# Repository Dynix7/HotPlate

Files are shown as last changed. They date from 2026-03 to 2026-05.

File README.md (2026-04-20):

# HotPlate
This is a design for an solder reflow hotplate controlled by an RP2040.

# Why I Made It
I made this PCB since I plan to solder more components in the future. But I currently only have an solder iron which is too big for smaller SMD components, so I can use this to easily solder those smaller components.

# Picture
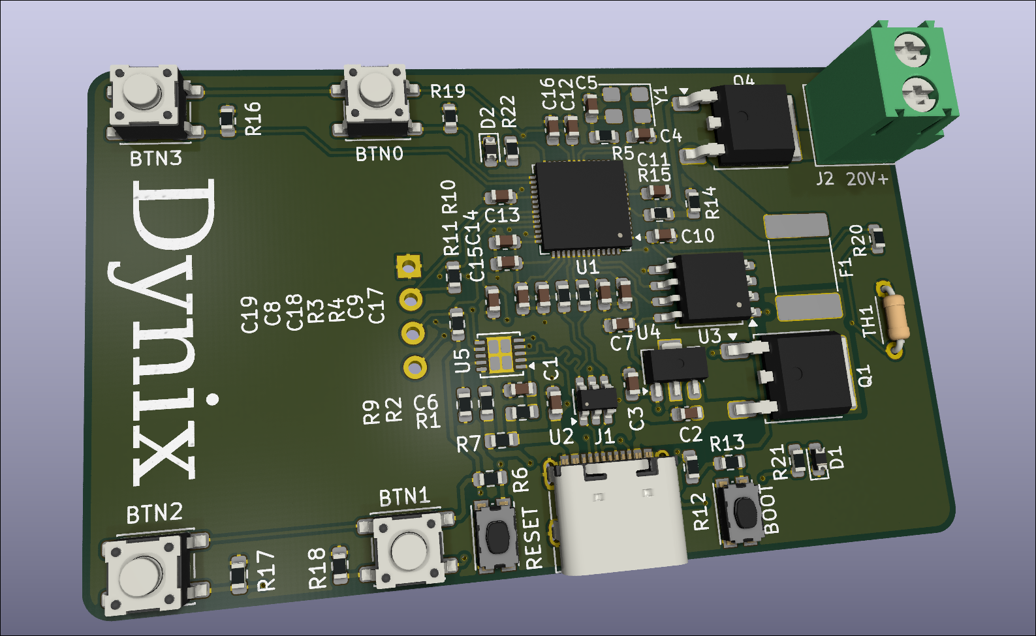
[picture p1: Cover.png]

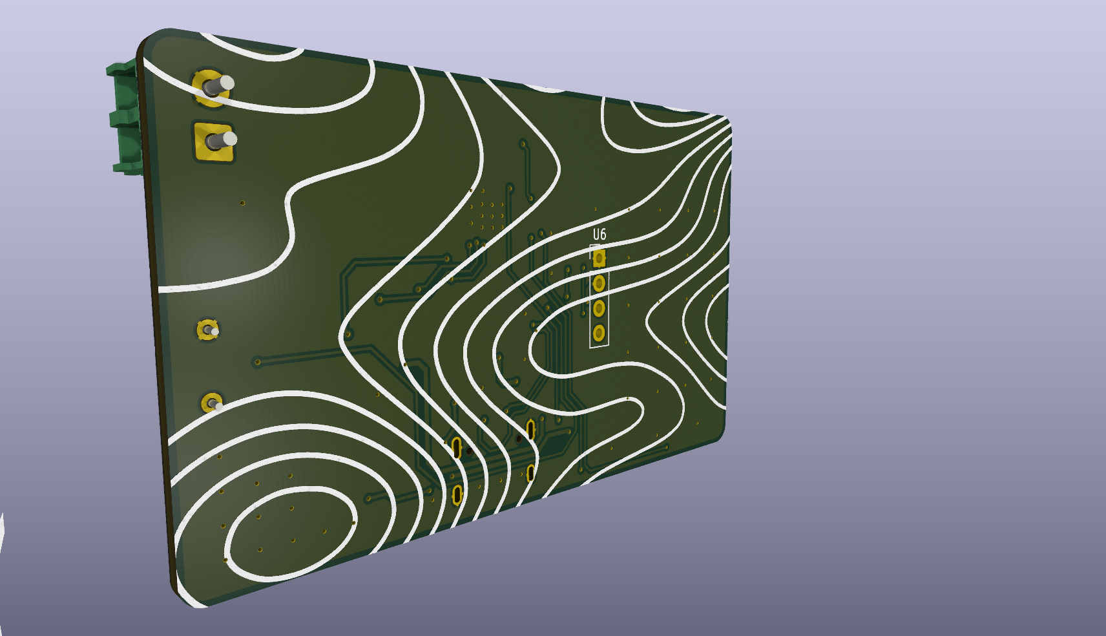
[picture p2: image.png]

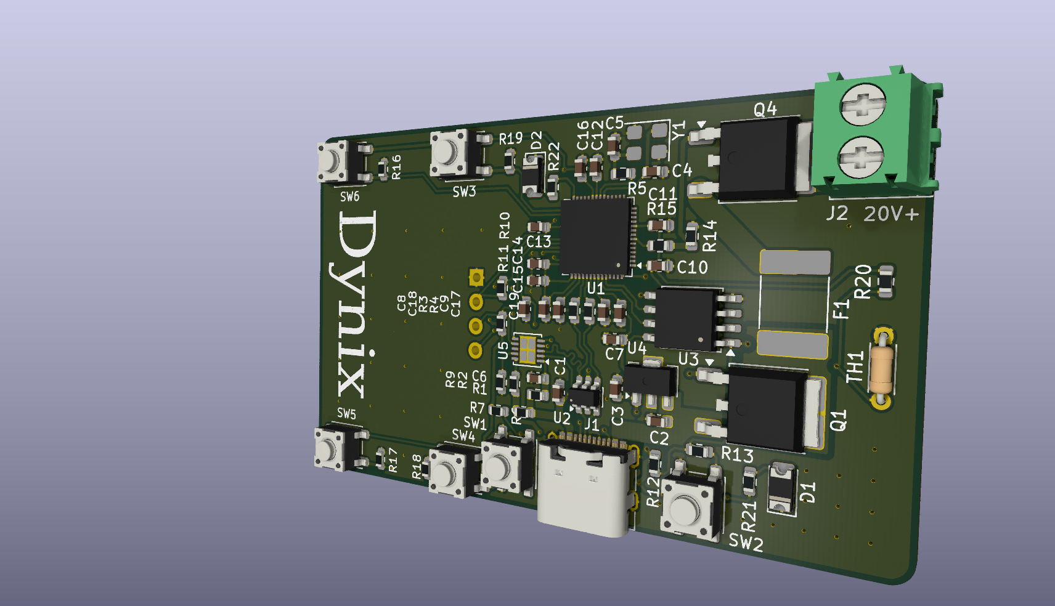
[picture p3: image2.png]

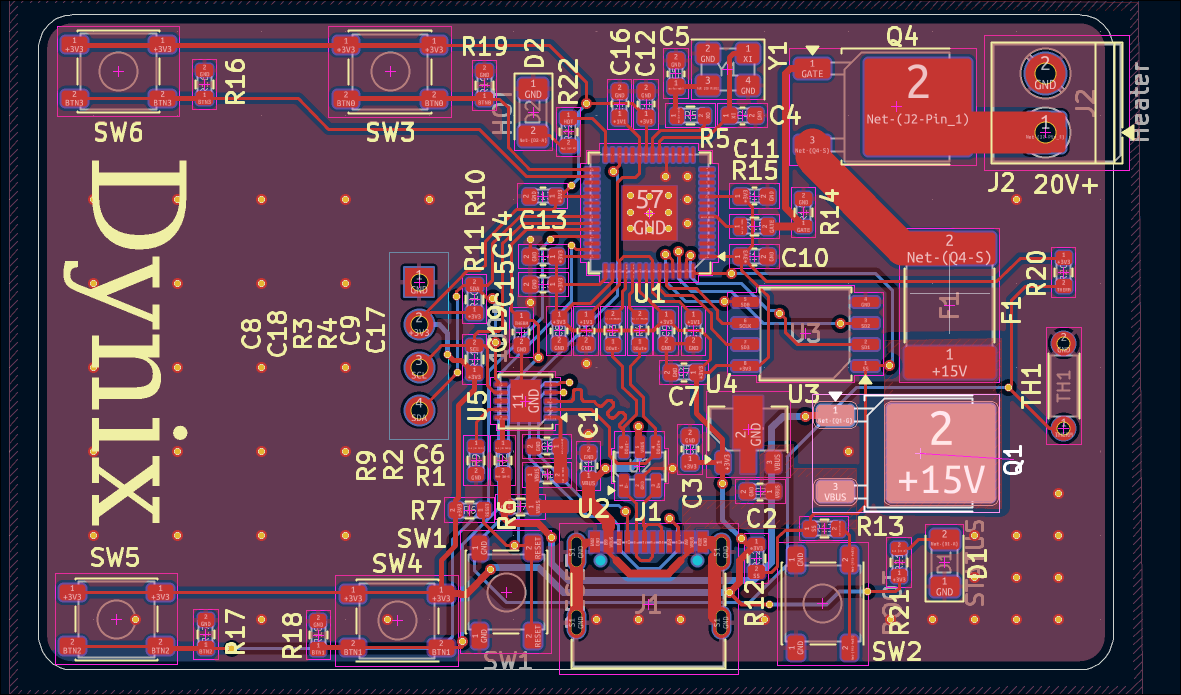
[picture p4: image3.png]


|Name |Purpose |Quantity|Total Cost (USD)|Link |Distributor|
|---|---|---|---|---|---|
|70mm round Polymide Heater|Heating Element |1 |3.92 |https://www.aliexpress.us/item/2255801077213882.html?mp=1|Aliexpress |
|PCB Stencil |For Manual PCB Assembly  |1 |7.11 | |JLCPCB |
|PCB |PCB for Build |5 |5.10 | |JLCPCB |
|100n Capacitor |Capacitor |100 |0.23 |https://www.lcsc.com/product-detail/C6119867.html |LCSC |
|1uF Capacitor |Capacitor |50 |0.27 |https://www.lcsc.com/product-detail/C59782.html |LCSC |
|10uF Capacitor |Capacitor |50 |0.40 |https://www.lcsc.com/product-detail/C19702.html |LCSC |
|12pF Capacitor |Crystal Load Capacitors  |100 |0.28 |https://www.lcsc.com/product-detail/C45359931.html |LCSC |
|10k Resistor |Resistor |100 |0.10 |https://www.lcsc.com/product-detail/C2930027.html |LCSC |
|1k Resistor |Resistor |100 |0.09 |https://www.lcsc.com/product-detail/C2907113.html |LCSC |
|5.1k Resistor |Resistor |100 |0.10 |https://www.lcsc.com/product-detail/C2907114.html |LCSC |
|27 Resistor |Resistor |100 |0.10 |https://www.lcsc.com/product-detail/C2907021.html |LCSC |
|2.7k Resistor |Resistor |100 |0.15 |https://www.lcsc.com/product-detail/C13167.html |LCSC |
|10 Resistor |Resistor |20 |0.04 |https://www.lcsc.com/product-detail/C22859.html |LCSC |
|49.9 Resistor |Resistor |100 |0.11 |https://www.lcsc.com/product-detail/C2930110.html |LCSC |
|22.6k Resistor |REsistor |100 |0.12 |https://www.lcsc.com/product-detail/C2999509.html |LCSC |
|LED |Indicator LEDs |50 |0.40 |https://www.lcsc.com/product-detail/C2827254.html |LCSC |
|100Ohm Resistor |Resistor |100 |0.10 |https://www.lcsc.com/product-detail/C2906981.html |LCSC |
|Push Button |Reset, Boot, Menu Buttons|20 |0.34 |https://www.lcsc.com/product-detail/C18078070.html |LCSC |
|SX3B12.000F1210F30 Crystal|Clock for RP2040 |5 |0.36 |https://www.lcsc.com/product-detail/C2901650.html |LCSC |
|LUTE 2920L500/30GR Fuse |Prevents Overheating |5 |0.74 |https://www.lcsc.com/product-detail/C19078763.html |LCSC |
|L78L33ACUTR |Voltage Regulator |5 |0.49 |https://www.lcsc.com/product-detail/C22358668.html |LCSC |
|USBLC6-2SC6 |Power Protection |5 |0.77 |https://www.lcsc.com/product-detail/C7519.html |LCSC |
|RP2040 |Microcontroller |1 |0.95 |https://www.lcsc.com/product-detail/C2040.html |LCSC |
|HUSB238 USB PD Chip | USB Power Delivery |1 |0.50 |https://www.lcsc.com/product-detail/C7471904.html |LCSC |
|W25Q32JVSSIQ Flash Chip |Storage of Program |5 |7.51 |https://www.lcsc.com/product-detail/C179173.html |LCSC |
|N-Channel MOSFET |Power Control |5 |0.58 |https://www.lcsc.com/product-detail/C2902884.html |LCSC |
|P-Channel MOSFET |Control Power |1 |0.34 |https://www.lcsc.com/product-detail/C5277951.html |LCSC |
|2 Pin Terminal Block |To Power Heating Element |5 |0.42 |https://www.lcsc.com/product-detail/C695629.html |LCSC |
|USB-C Receptacle |Power |5 |0.41 |https://www.lcsc.com/product-detail/C2988369.html |LCSC |
|NTC Thermistor 100kΩ |Thermometer |5 |1.28 |https://www.lcsc.com/product-detail/C5355638.html |LCSC |

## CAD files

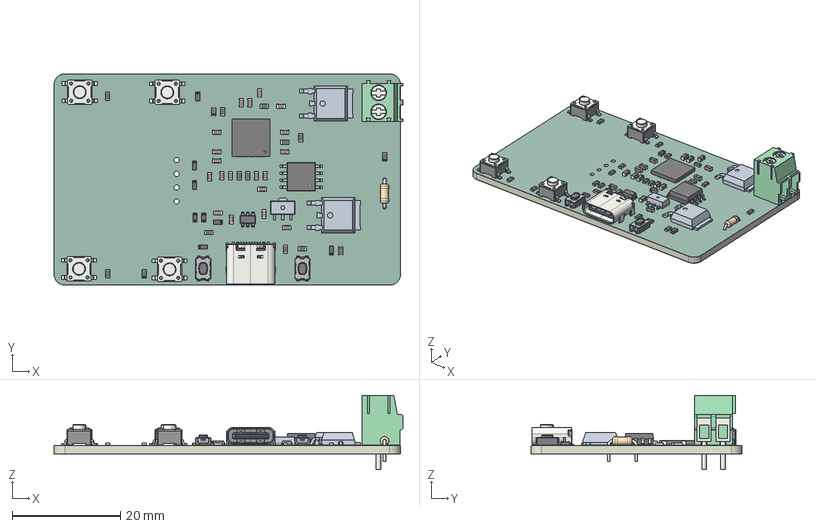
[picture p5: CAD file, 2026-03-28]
HotPlate/plate.step
64.4 x 39.0 x 13.7 mm
plate 1.1.1
C_0603_1608Metric x 19
R_Axial_DIN0204_L3.6mm_D1.6mm_P5.08mm_Horizontal
R_0603_1608Metric x 21
SOT-23-6
QFN-56-1EP_7x7mm_P0.4mm_EP3.2x3.2mm
SW_Push_1P1T_NO_CK_KMR2 x 2
TerminalBlock_Phoenix_PT-1,5-2-3.5-H_1x02_P3.50mm_Horizontal
USB_C_Receptacle_GCT_USB4105-xx-A_16P_TopMnt_Horizontal
SW_SPST_PTS647Sx38 x 4
plate 1.27.1 x 2
SOIC-8_5.3x5.3mm_P1.27mm
D_0603_1608Metric x 2
HotPlate_soldermask x 2
HotPlate_PCB

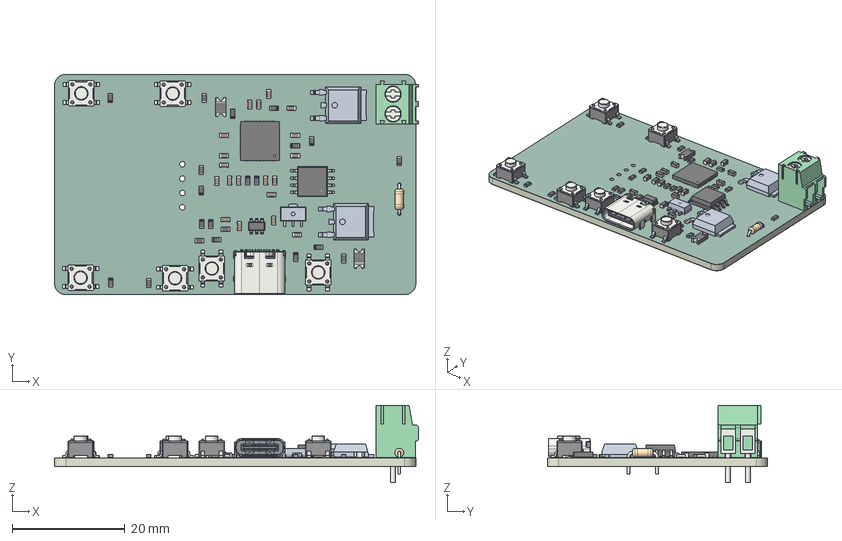
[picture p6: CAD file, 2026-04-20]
pcb.step
64.4 x 39.0 x 13.7 mm
pcb 1.1.1
C_0603_1608Metric x 19
R_Axial_DIN0204_L3.6mm_D1.6mm_P5.08mm_Horizontal
R_0603_1608Metric x 21
SOT-23-6
QFN-56-1EP_7x7mm_P0.4mm_EP3.2x3.2mm
SW_SPST_PTS647Sx38 x 6
TerminalBlock_Phoenix_PT-1,5-2-3.5-H_1x02_P3.50mm_Horizontal
USB_C_Receptacle_GCT_USB4105-xx-A_16P_TopMnt_Horizontal
pcb 1.27.1 x 2
SOIC-8_5.3x5.3mm_P1.27mm
D_1206_3216Metric x 2
HotPlate_soldermask x 2
HotPlate_PCB

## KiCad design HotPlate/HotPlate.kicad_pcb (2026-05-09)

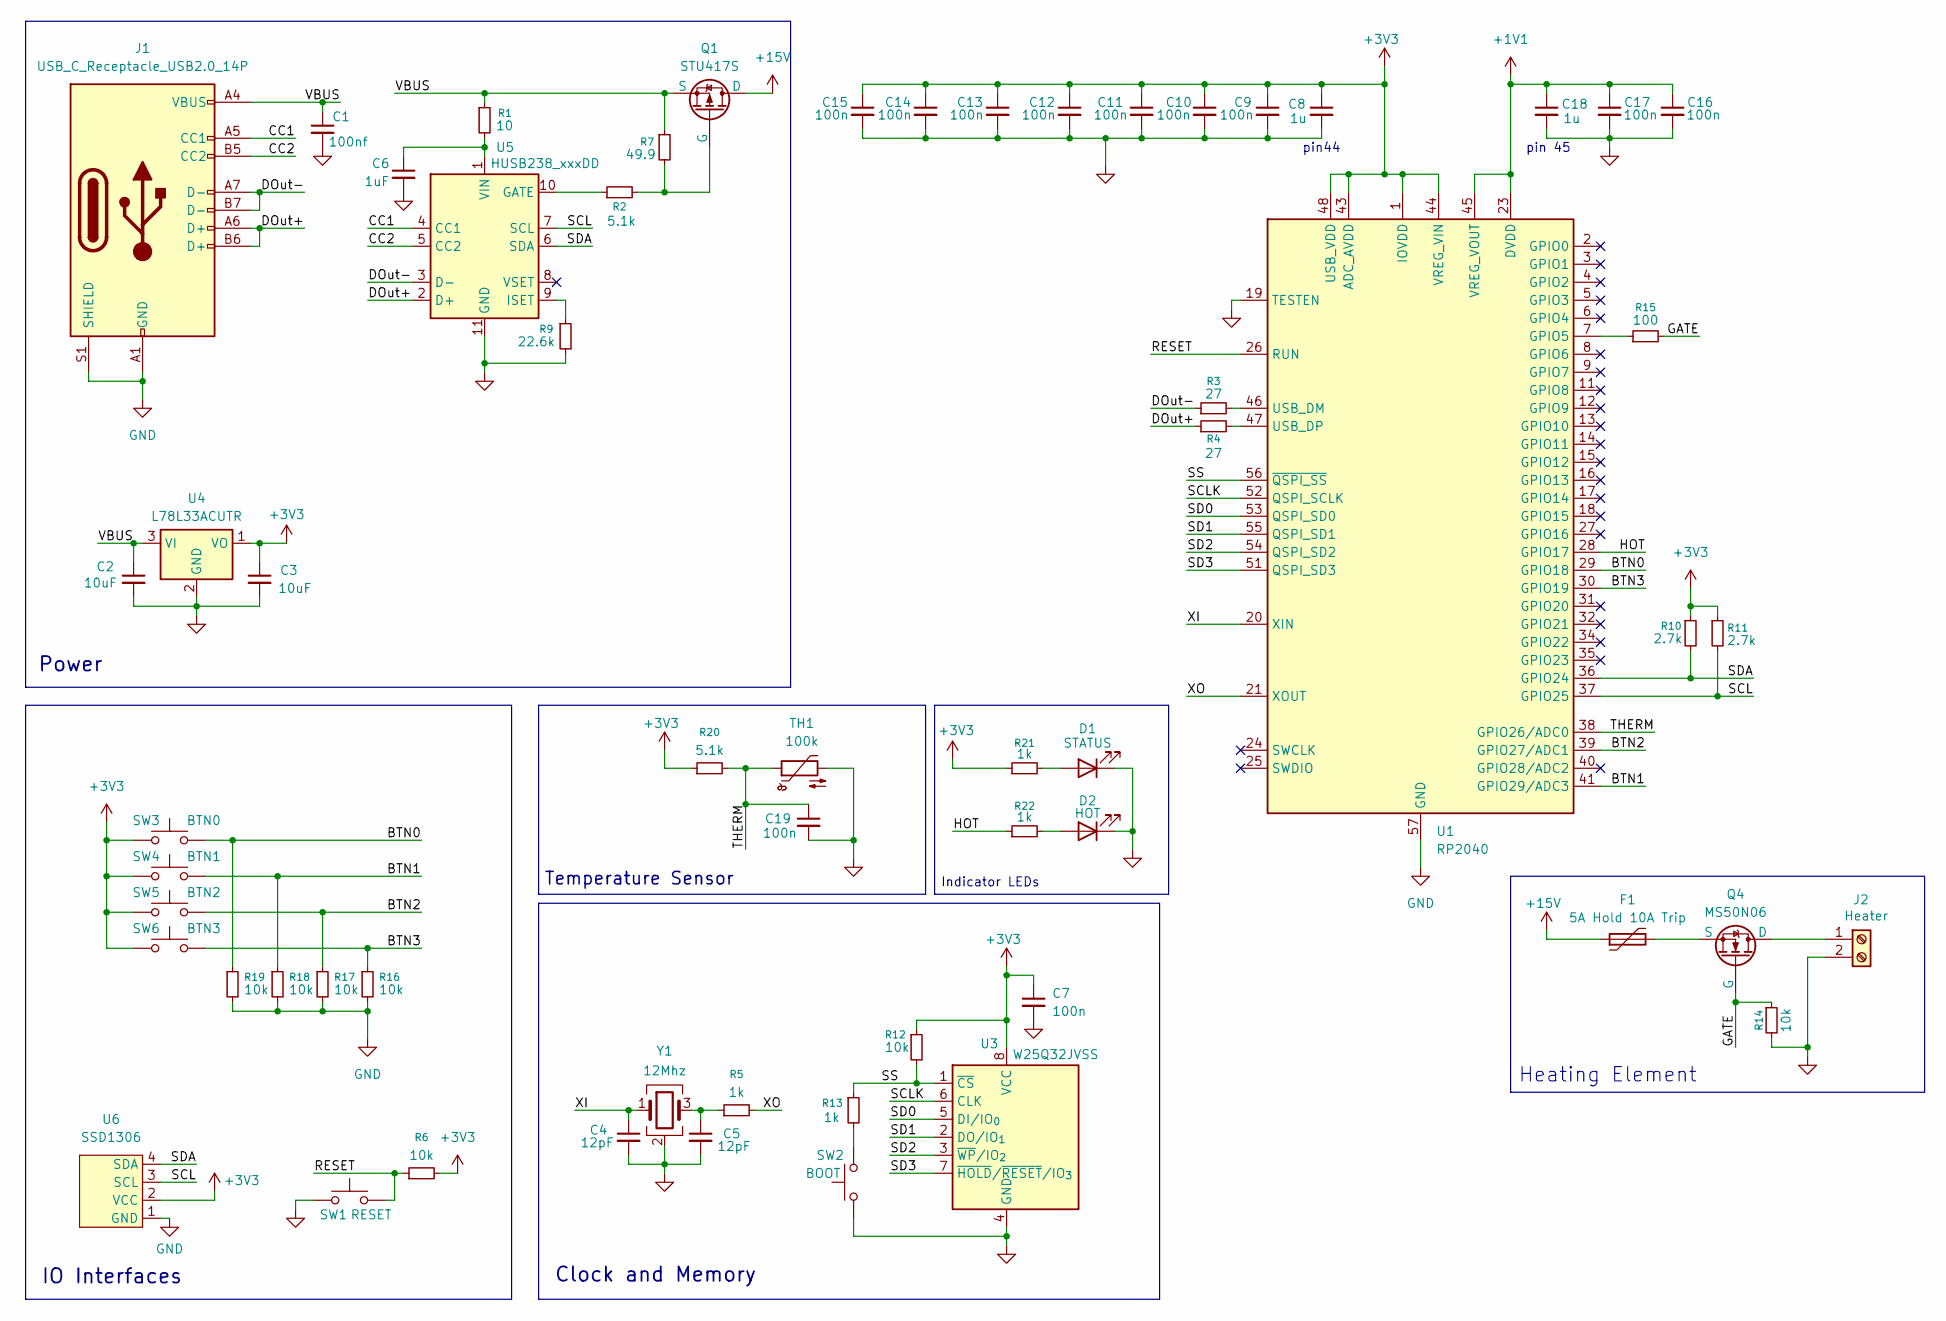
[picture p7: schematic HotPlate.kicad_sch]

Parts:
C1: 100nf; C_0603_1608Metric
C2, C3: 10uF; C_0603_1608Metric
C4, C5: 12pF; C_0603_1608Metric
C6: 1uF; C_0603_1608Metric
C7, C9, C10, C11, C12, C13, C14, C15, C16, C17, C19: 100n; C_0603_1608Metric
C8, C18: 1u; C_0603_1608Metric
D1: STATUS; D_1206_3216Metric
D2: HOT; D_1206_3216Metric
F1: 5A Hold 10A Trip; Fuse_2920_7451Metric
J1: USB_C_Receptacle_USB2.0_14P; USB_C_Receptacle_G-Switch_GT-USB-7010ASV
J2: Heater; TerminalBlock_Phoenix_PT-1,5-2-3.5-H_1x02_P3.50mm_Horizontal
Q1: STU417S; TO-252-2
Q4: MS50N06; TO-252-2
R1: 10; R_0603_1608Metric
R2, R20: 5.1k; R_0603_1608Metric
R3, R4: 27; R_0603_1608Metric
R5, R13, R21, R22: 1k; R_0603_1608Metric
R6, R12, R14, R16, R17, R18, R19: 10k; R_0603_1608Metric
R7: 49.9; R_0603_1608Metric
R9: 22.6k; R_0603_1608Metric
R10, R11: 2.7k; R_0603_1608Metric
R15: 100; R_0603_1608Metric
SW1: RESET; SW_SPST_PTS647_Sx38
SW2: BOOT; SW_SPST_PTS647_Sx38
SW3: BTN0; SW_SPST_PTS647_Sx38
SW4: BTN1; SW_SPST_PTS647_Sx38
SW5: BTN2; SW_SPST_PTS647_Sx38
SW6: BTN3; SW_SPST_PTS647_Sx38
TH1: 100k; R_Axial_DIN0204_L3.6mm_D1.6mm_P5.08mm_Horizontal
U1: RP2040; QFN-56-1EP_7x7mm_P0.4mm_EP3.2x3.2mm
U3: W25Q32JVSS; SOIC-8_5.3x5.3mm_P1.27mm
U4: L78L33ACUTR; SOT-89-3
U5: HUSB238_xxxDD; WDFN-10-1EP_3x3mm_P0.5mm_EP1.8x2.5mm
U6: SSD1306; PinHeader_1x04_P2.54mm_Vertical
Y1: 12Mhz; Oscillator_SMD_SeikoEpson_SG8002CE-4Pin_3.2x2.5mm

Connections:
+1V1: C16.1, C17.1, C18.1, U1.23 (DVDD), U1.45 (VREG_VOUT), U1.50 (DVDD)
+3V3: C3.1, C7.1, C8.1, C9.1, C10.1, C11.1, C12.1, C13.1, C14.1, C15.1, R6.2, R10.1, R11.1, R12.1, R20.1, R21.1, SW3.1, SW4.1, SW5.1, SW6.1, U1.1 (IOVDD), U1.10 (IOVDD), U1.22 (IOVDD), U1.33 (IOVDD), U1.42 (IOVDD), U1.43 (ADC_AVDD), U1.44 (VREG_VIN), U1.48 (USB_VDD), U1.49 (IOVDD), U3.8 (VCC), U4.1 (VO), U6.2 (VCC)
+15V: F1.1, Q1.2 (D)
/BTN0: R19.1, SW3.2, U1.29 (GPIO18)
/BTN1: R18.1, SW4.2, U1.41 (GPIO29/ADC3)
/BTN2: R17.1, SW5.2, U1.39 (GPIO27/ADC1)
/BTN3: R16.1, SW6.2, U1.30 (GPIO19)
/CC1: J1.A5 (CC1), U5.4 (CC1)
/CC2: J1.B5 (CC2), U5.5 (CC2)
/DOut+: J1.A6 (D+), J1.B6 (D+), R4.1, U5.2 (D+)
/DOut-: J1.A7 (D-), J1.B7 (D-), R3.1, U5.3 (D-)
/GATE: Q4.1 (G), R14.1, R15.2
/HOT: R22.1, U1.28 (GPIO17)
/RESET: R6.1, SW1.2, U1.26 (RUN)
/SCL: R11.2, U1.37 (GPIO25), U5.7 (SCL), U6.3 (SCL)
/SCLK: U1.52 (QSPI_SCLK), U3.6 (CLK)
/SD0: U1.53 (QSPI_SD0), U3.5 (DI/IO_{0})
/SD1: U1.55 (QSPI_SD1), U3.2 (DO/IO_{1})
/SD2: U1.54 (QSPI_SD2), U3.3 (~WP/IO_{2})
/SD3: U1.51 (QSPI_SD3), U3.7 (~HOLD/~RESET/IO_{3})
/SDA: R10.2, U1.36 (GPIO24), U5.6 (SDA), U6.4 (SDA)
/SS: R12.2, R13.1, U1.56 (~QSPI_SS), U3.1 (~CS)
/THERM: C19.1, R20.2, TH1.1, U1.38 (GPIO26/ADC0)
/VBUS: C1.1, C2.1, J1.A4 (VBUS), J1.A9 (VBUS), J1.B4 (VBUS), J1.B9 (VBUS), Q1.3 (S), R1.1, R7.1, U4.3 (VI)
/XI: C4.1, U1.20 (XIN), Y1.1
/XO: R5.2, U1.21 (XOUT)
GND: C1.2, C2.2, C3.2, C4.2, C5.2, C6.2, C7.2, C8.2, C9.2, C10.2, C11.2, C12.2, C13.2, C14.2, C15.2, C16.2, C17.2, C18.2, C19.2, D1.1 (K), D2.1 (K), J1.A1 (GND), J1.A12 (GND), J1.B1 (GND), J1.B12 (GND), J1.S1 (SHIELD), J2.2, R9.2, R14.2, R16.2, R17.2, R18.2, R19.2, SW1.1, SW2.1, TH1.2, U1.19 (TESTEN), U1.57 (GND), U3.4 (GND), U4.2 (GND), U5.11 (GND), U6.1 (GND), Y1.2 (G), Y1.4 (G)
unnamed: C5.1, R5.1, Y1.3
unnamed: D1.2 (A), R21.2
unnamed: D2.2 (A), R22.2
unnamed: J2.1, Q4.2 (D)
unnamed: Q1.1 (G), R2.2, R7.2
unnamed: F1.2, Q4.3 (S)
unnamed: R13.2, SW2.2
unnamed: R15.1, U1.7 (GPIO5)
unnamed: R3.2, U1.46 (USB_DM)
unnamed: R4.2, U1.47 (USB_DP)
unnamed: R2.1, U5.10 (GATE)
unnamed: R9.1, U5.9 (ISET)
unnamed: C6.1, R1.2, U5.1 (VIN)

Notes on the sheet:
Power
IO Interfaces
Heating Element
pin44
Temperature Sensor
Clock and Memory
Indicator LEDs
pin 45

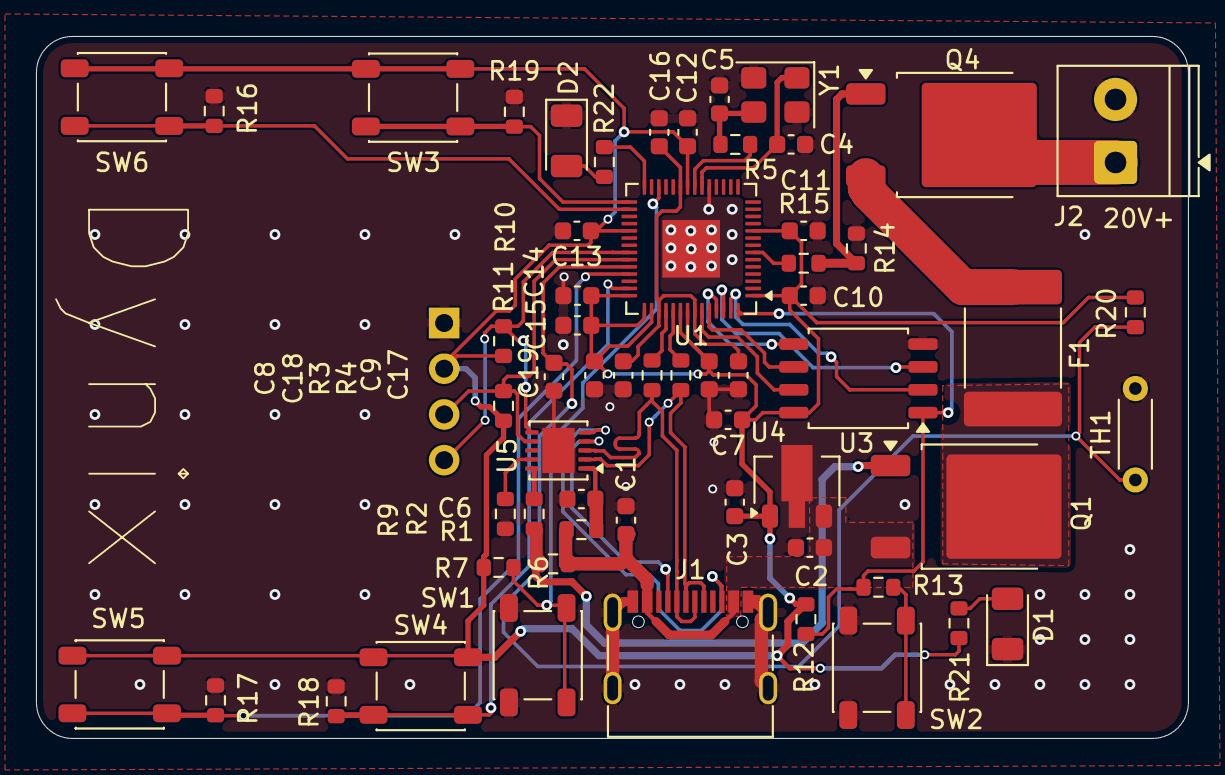
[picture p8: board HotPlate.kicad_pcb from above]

Board: 2 copper layers, 64.0 x 39.0 mm, 60 parts (1 on the bottom side), 40 nets.

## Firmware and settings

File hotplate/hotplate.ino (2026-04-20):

#include <Wire.h>
#include <Adafruit_SSD1306.h>
#include <Thermistor.h>
#include <NTC_Thermistor.h>

#include "thermistor.hpp"
#include "temperature.hpp"
#include "screen.hpp"
#include "helper.hpp"
#include "config.hpp"


NTC_Thermistor thermistor(THERM, REF_RESISTOR, NTC_RESISTANCE, NTC_REF_TEMP, B_VALUE, ANALOG_RES);
Adafruit_SSD1306 OLED_1306(SCREEN_WIDTH, SCREEN_HEIGHT, SCREEN_WIRE, OLED_RESET);

enum PLATESTATE currentState = STARTUP;

struct HEATINGPROFILE profile = {
    .targetTemps = {150.0, 220.0}, // Soak Temp, Reflow Temp-Celsius
    .targetTimes = {100, 60}, //Length of Soak, Length of Reflow-Seconds
    .targetRates = {2.5, 2.5, 3.5} // Start->Soak, Soak->Reflow, Reflow->End  -  Celsius/Second
}

HotPlateScreen SCREEN(&OLED_1306, &profile, &currentState);

void setup() {
    Serial.begin(115200);

    //I2C stuff
    Wire.begin();
    Wire.setSDA(SDA);
    Wire.setSCL(SCL);

    // Pinout Setup
    pinMode(BTN0, INPUT);
    pinMode(BTN1, INPUT);
    pinMode(BTN2, INPUT);
    pinMode(BTN3, INPUT);

    pinMode(GATE, OUTPUT);
    pinMode(HOT, OUTPUT); //LED

    pinMode(THERM, INPUT);

    SCREEN.initScreen();
}

void loop() {

  SCREEN.updateScreen();

}

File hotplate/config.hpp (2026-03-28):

#pragma once

// Pinouts
#define SDA 24
#define SCL 25

#define HOT 17

#define BTN0 18
#define BTN1 29
#define BTN2 27
#define BTN3 19

#define GATE 5

#define THERM A0

//Thermistor Reading Values

#define NTC_RESISTANCE 100000
#define NTC_REF_TEMP 25
#define REF_RESISTOR 5100
#define ANALOG_RES 4095
#define B_VALUE 3950

#define READ_RATE 1.0/20

//Screen Related Variables
#define SCREEN_WIDTH 128
#define SCREEN_HEIGHT 64
#define OLED_RESET -1
#define SCREEN_ADDRESS 0x3C
#define SCREEN_WIRE &Wire
#define SCREEN_REFRESH_RATE 1.0/10


enum PLATESTATE {
    INIT,
    IDLE,
    ADJUST_TEMP,
    ADJUST_TIMES,
    ADJUST_RATES,
    HEATING,
    STOPPED
}

enum HEATSTATE {
    START,
    RAMPSOAK,
    SOAK,
    RAMPREFLOW,
    REFLOW,
    COOLING,
    END
}
//Stores the Reflow  Profile
struct HEATINGPROFILE {
    enum HEATSTATE heatState = START;

    double targetTemps[2] = {0}; // Soak Temp, Reflow Temp-Celsius
    double targetTimes[2] = {0}; //Length of Soak Plataeu, Length of Reflow Plataeu-Seconds
    double targetRates[3] = {0}; // Start->Soak, Soak->Reflow, Reflow->End  -  Celsius/Second

    double currentTempTarget = 0.0;

    double timeFromStart = 0.0;
    double currentTempC = 0.0;
    double currentTempF = 0.0;
}

struct CONTROL {
    double Kp = 0.0;
    double Ki = 0.0;
    
    double deltaTime = READ_RATE;
    
    double error = 0.0;
    double prevError = 0.0;
}

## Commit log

2026-03-08 Initial USB and RP2040 Schematic
    [HotPlate.kicad_pcb, HotPlate.kicad_sch]
2026-03-09 Wire up power delivery, and memory
    [HotPlate.kicad_sch]
2026-03-10 Re-add buttons and add thermistor
    [HotPlate.kicad_sch]
2026-03-13 Wire Buttons, screen, thermistor, fuse
    [HotPlate.kicad_sch]
2026-03-14 Status LEDs
    [HotPlate.kicad_sch]
2026-03-15 Begin PCB placements and routing
    [HotPlate.kicad_pcb, HotPlate.kicad_sch]
2026-03-15 Finish routing
    [HotPlate.kicad_pcb, HotPlate.kicad_sch]
2026-03-19 Minor placement changes and ground vias
    [HotPlate.kicad_pcb]
2026-03-21 Started Code and Added Name to PCB
    [HotPlate.kicad_pcb]
2026-03-24 Minor code changes
    [HotPlate-B_Cu.gbr, HotPlate-B_Mask.gbr, HotPlate-B_Paste.gbr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]
2026-03-28 code for screen
    [HotPlate.kicad_pcb, plate.step]
2026-04-19 add ibom
    [HotPlate.kicad_pcb]
2026-04-19 Change LED size
    [HotPlate.kicad_pcb, HotPlate.kicad_sch]
2026-04-19 Change button footprint
    [HotPlate.kicad_pcb, HotPlate.kicad_sch]
2026-05-09 Remove the USBLC6 since i forgot that im using 20v and not 5v
    [HotPlate.kicad_pcb, HotPlate.kicad_sch]
